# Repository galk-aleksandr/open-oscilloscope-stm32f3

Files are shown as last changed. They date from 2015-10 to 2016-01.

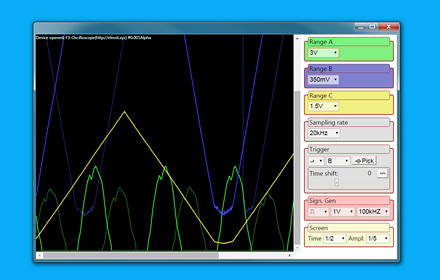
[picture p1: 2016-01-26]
chromoscope/small_tile.png

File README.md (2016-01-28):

##Open-Source Oscilloscope based on STM32F3-DISCOVERY board

Some ideas got from Tomasz Ostrowski's [Miniscope](http://tomeko.net/miniscope_v4/index.php?lang=en).
Tomasz has a bunch of ready-to-use-devices, and I have the only preliminary schematics and raw prototype.

The main idea is to build PC-oscilloscope. Hardware is ST Microelectronics development board
[STM32F3-DISCOVERY](http://www.st.com/web/catalog/tools/FM116/SC959/SS1532/PF254044) plus small additional board with simple protection circuits and basic voltage dividers.

###License:
[MIT](license.txt)

###Hardware variants
* Naked Discovery(Nucleo)
 * _No overvoltage protection_
 * Input voltage: 0..3V uni-polar
* [Shield board](#shield-board) + Discovery(Nucleo)
 * Overvoltage protection
 * Input voltage: 0..45V uni-polar
 * Input impedance ~1MOhm

###Features(Milestone 1):
* PC connectivity - USB
* Platform independent desktop(Chrome App)
* Minimal voltage resolution 46&mu;V
* Internal SYNC
* Simple signal generator (triangle, white noise)
* 12-bit sampling
* Channel GAIN up to x16
* Three channels
* Up to 5M samples/sec

###Features(Milestone 2):
* Extended signal generator(meander, sine wave, custom shape)
* Nucleo-F303RE board support
* External SYNC

###Shield board:
[PCB sources](https://github.com/elmot/open-oscilloscope-stm32f3/tree/schematics)(MIT license)

Schematics
Board

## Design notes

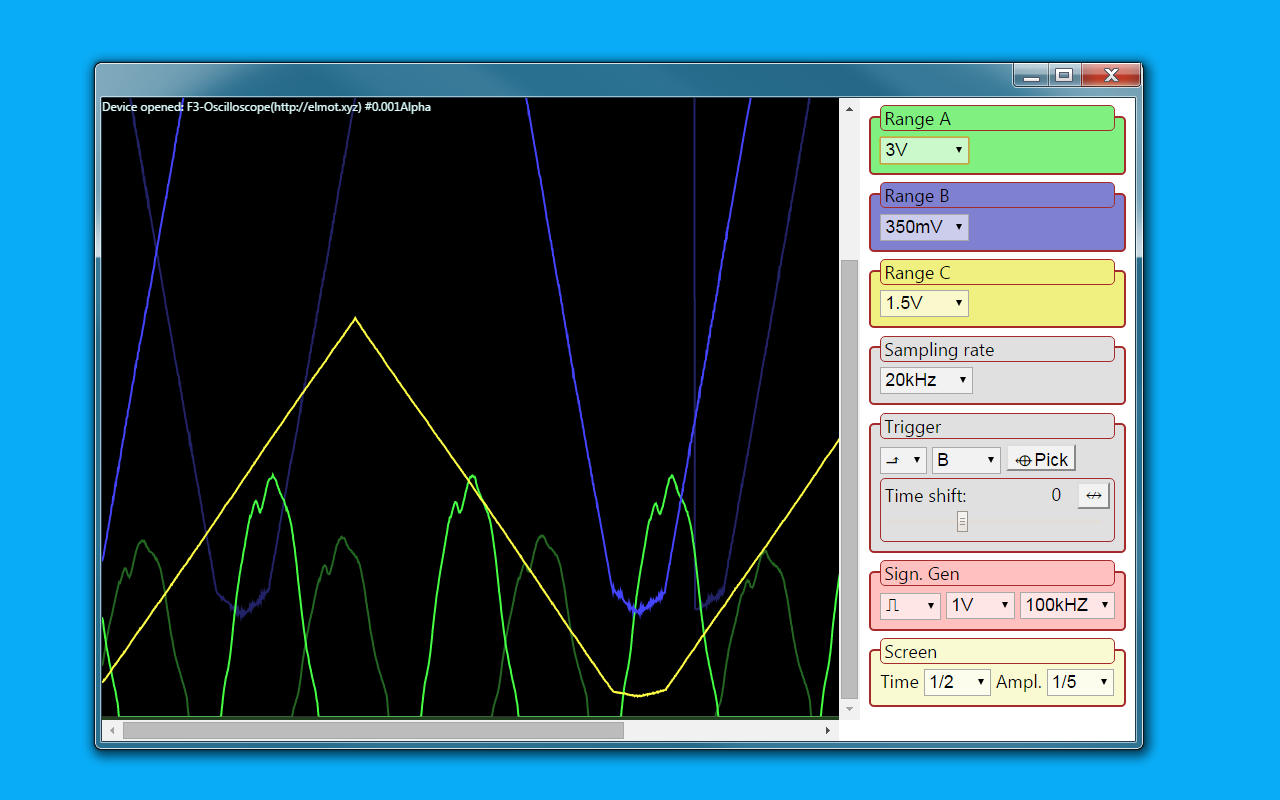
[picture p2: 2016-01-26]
chromoscope/screenshot.png

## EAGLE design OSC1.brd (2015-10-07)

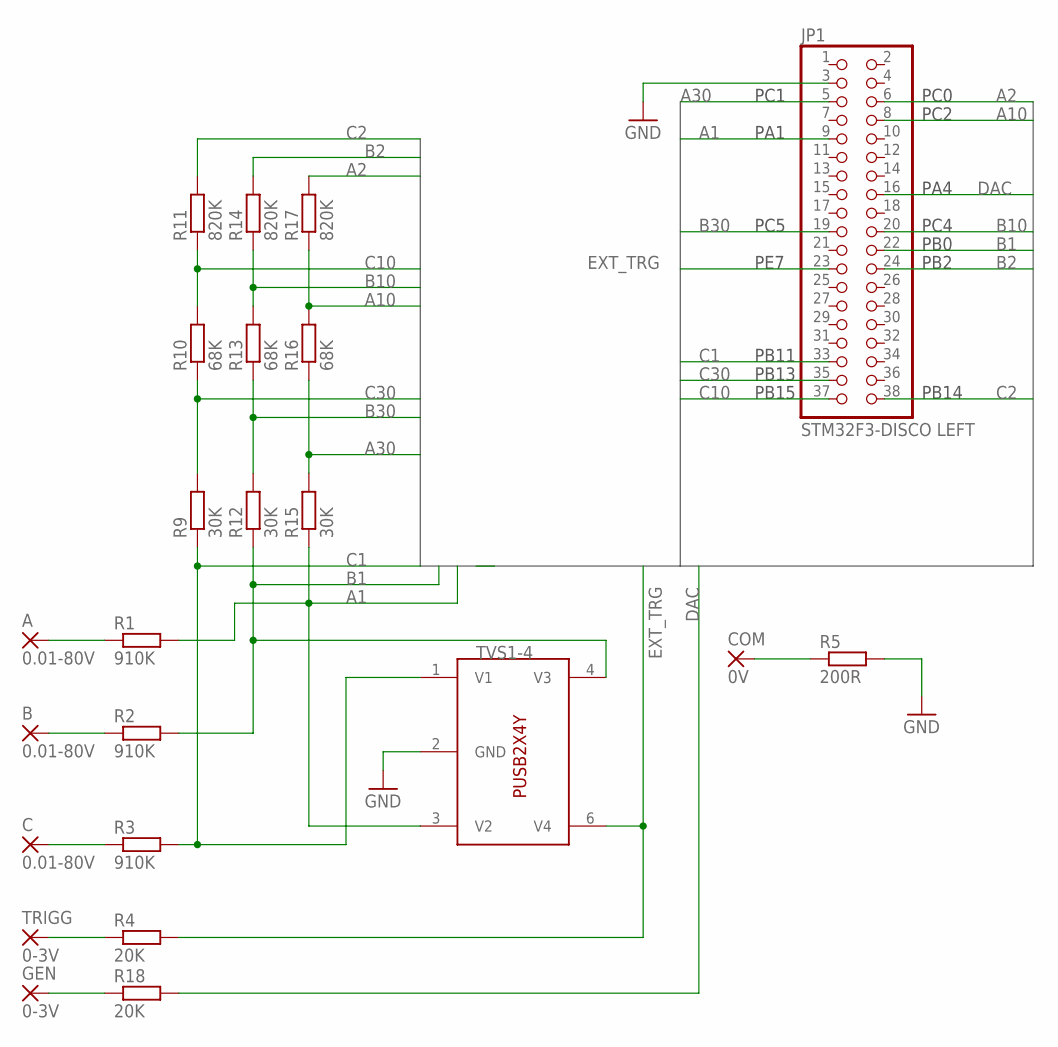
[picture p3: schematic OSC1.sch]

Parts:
A: 0.01-80V; 2,54/0,8
B: 0.01-80V; 2,54/0,8
C: 0.01-80V; 2,54/0,8
COM: 0V; 2,54/0,8
GEN: 0-3V; 2,54/0,8
JP1: STM32F3-DISCO LEFT; 2X19
R1, R2, R3: 910K; R1206
R4, R18: 20K; R1206
R5: 200R; R1206
R9, R12, R15: 30K; R1206
R10, R13, R16: 68K; R1206
R11, R14, R17: 820K; R1206
TRIGG: 0-3V; 2,54/0,8
TVS1-4: PUSB2X4Y; SOT363_PHILIPS

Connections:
A1: JP1.9, R1.2, R15.1, TVS1-4.3 (V2)
A2: JP1.6, R17.2
A10: JP1.8, R16.2, R17.1
A30: JP1.5, R15.2, R16.1
B1: JP1.22, R2.2, R12.1, TVS1-4.4 (V3)
B2: JP1.24, R14.2
B10: JP1.20, R13.2, R14.1
B30: JP1.19, R12.2, R13.1
C1: JP1.33, R3.2, R9.1, TVS1-4.1 (V1)
C2: JP1.38, R11.2
C10: JP1.37, R10.2, R11.1
C30: JP1.35, R9.2, R10.1
DAC: JP1.16, R18.2
EXT_TRG: JP1.23, R4.2, TVS1-4.6 (V4)
GND: JP1.3, R5.2, TVS1-4.2 (GND)
unnamed: COM.1, R5.1
unnamed: A.1, R1.1
unnamed: R4.1, TRIGG.1
unnamed: C.1, R3.1
unnamed: B.1, R2.1
unnamed: GEN.1, R18.1

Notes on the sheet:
PA1
PB11
PB0
PA4
PC1
PC0
PC2
PB2
PC4
PC5
PB13
PB14
PB15
PE7

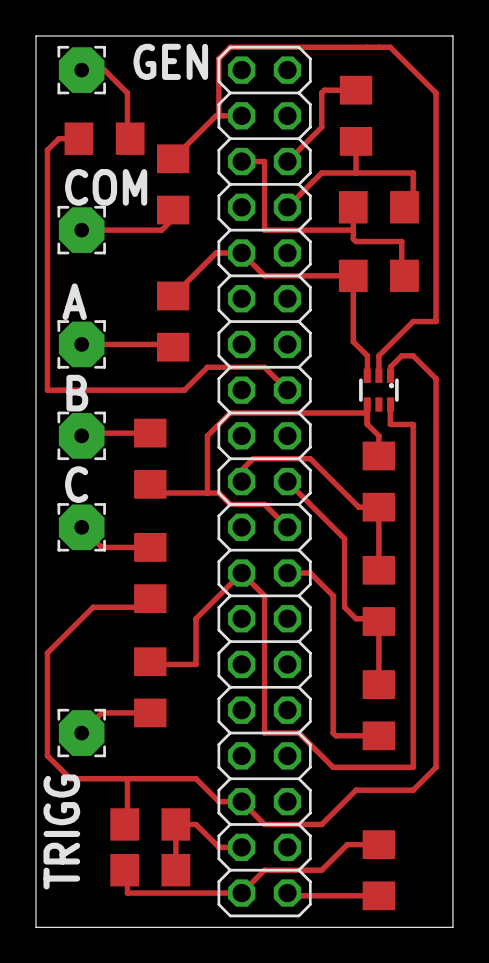
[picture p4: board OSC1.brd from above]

Board: 2 copper layers, 23.2 x 49.5 mm, 23 parts (0 on the bottom side), 21 nets.

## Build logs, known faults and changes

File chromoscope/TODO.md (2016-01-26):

## Firmware
* ADC sampling time
* get rid of vertical lines
* broken line if pre-trigger
* Trigger histeresis
* Shield board detection
* Config send
* External trigger?

## PC software
* External trigger
* Grid over canvas
* Measurements
* Help/Documentation
* Naked board config

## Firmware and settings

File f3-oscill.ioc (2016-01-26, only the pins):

Mcu.UserName=STM32F303VCTx
PA0.GPIO_Label=B1 [Blue PushButton]
PA0.Signal=GPIO_Input
PA1.GPIO_Label=OSCILLOSCOPE-A1[OPAMP1-VINP]
PA1.Signal=OPAMP1_VINP
PA11.GPIO_Label=DM
PA11.Signal=USB_DM
PA12.GPIO_Label=DP
PA12.Signal=USB_DP
PA13.GPIO_Label=SWDIO
PA13.Signal=SYS_JTMS-SWDIO
PA14.GPIO_Label=SWCLK
PA14.Signal=SYS_JTCK-SWCLK
PA2.Signal=OPAMP1_VOUT
PA3.Signal=USART2_RX
PA4.GPIO_Label=OSCILLOSCOPE-GEN[DAC-OUT1]
PA4.Signal=COMP_DAC1_group
PA5.GPIO_Label=SPI1_SCK [L3GD20_SCL/SPC]
PA5.Signal=SPI1_SCK
PA6.GPIO_Label=SPI1_MISO [L3GD20_SA0/SDO]
PA6.Signal=SPI1_MISO
PA7.GPIO_Label=SPI1_MISO [L3GD20_SDA/SDI/SDO]
PA7.Signal=SPI1_MOSI
PB0.GPIO_Label=OSCILLOSCOPE-B1[OPAMP3-VINP]
PB0.Signal=OPAMP3_VINP
PB1.Signal=OPAMP3_VOUT
PB11.GPIO_Label=OSCILLOSCOPE-C1[OPAMP4-VINP]
PB11.Signal=OPAMP4_VINP
PB12.Signal=OPAMP4_VOUT
PB13.GPIO_Label=OSCILLOSCOPE-C30
PB13.Signal=GPIO_Output
PB14.GPIO_Label=OSCILLOSCOPE-C2
PB14.Signal=GPIO_Output
PB15.GPIO_Label=OSCILLOSCOPE-C10
PB15.Signal=GPIO_Output
PB2.GPIO_Label=OSCILLOSCOPE-B2
PB2.Signal=GPIO_Output
PB3.GPIO_Label=SWO
PB3.Signal=SYS_JTDO-TRACESWO
PB6.GPIO_Label=I2C1_SCL [LSM303DLHC_SCL]
PB6.Signal=I2C1_SCL
PB7.GPIO_Label=I2C1_SDA [LSM303DLHC_SDA]
PB7.Signal=I2C1_SDA
PC0.GPIO_Label=OSCILLOSCOPE-A2
PC0.Signal=GPIO_Output
PC1.GPIO_Label=OSCILLOSCOPE-A30
PC1.Signal=GPIO_Output
PC14-OSC32_IN.GPIO_Label=OSC32_IN
PC14-OSC32_IN.Signal=RCC_OSC32_IN
PC15-OSC32_OUT.GPIO_Label=OSC32_OUT
PC15-OSC32_OUT.Signal=RCC_OSC32_OUT
PC2.GPIO_Label=OSCILLOSCOPE-A10
PC2.Signal=GPIO_Output
PC4.GPIO_Label=OSCILLOSCOPE-B10
PC4.Signal=GPIO_Output
PC5.GPIO_Label=OSCILLOSCOPE-B30
PC5.Signal=GPIO_Output
PD5.Signal=USART2_TX
PE0.GPIO_Label=MEMS_INT1 [L3GD20_INT1]
PE0.Signal=GPXTI0
PE1.GPIO_Label=MEMS_INT2 [L3GD20_DRDY/INT2]
PE1.Signal=GPXTI1
PE10.GPIO_Label=LD5 [Orange Led]
PE10.Signal=GPIO_Output
PE11.GPIO_Label=LD7 [Green Led]
PE11.Signal=GPIO_Output
PE12.GPIO_Label=LD9 [Blue Led]
PE12.Signal=GPIO_Output
PE13.GPIO_Label=LD10 [Red Led]
PE13.Signal=GPIO_Output
PE14.GPIO_Label=LD8 [Orange Led]
PE14.Signal=GPIO_Output
PE15.GPIO_Label=LD6 [Green Led]
PE15.Signal=GPIO_Output
PE2.GPIO_Label=DRDY [LSM303DLHC_DRDY]
PE2.Signal=GPXTI2
PE3.GPIO_Label=CS_I2C/SPI [L3GD20_CS_I2C/SPI]
PE3.Signal=GPIO_Output
PE4.GPIO_Label=MEMS_INT3 [LSM303DLHC_INT1]
PE4.Signal=GPXTI4
PE5.GPIO_Label=MEMS_INT4 [LSM303DLHC_INT2]
PE5.Signal=GPXTI5
PE7.GPIO_Label=OSCILLOSCOPE-EXT_SYNC[COMP4_INP]
PE7.Signal=COMP4_INP
PE8.GPIO_Label=LD4 [Blue Led]
PE8.Signal=GPIO_Output
PE9.GPIO_Label=LD3 [Red Led]
PE9.Signal=GPIO_Output
PF0-OSC_IN.GPIO_Label=OSC_IN
PF0-OSC_IN.Signal=RCC_OSC_IN
PF1-OSC_OUT.GPIO_Label=OSC_OUT
PF1-OSC_OUT.Signal=RCC_OSC_OUT

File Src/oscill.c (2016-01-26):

#include "string.h"
#include "stdbool.h"
#include "oscill.h"
#include "usbd_oscill_if.h"
#include "arm_math.h"

uint16_t bufferA[FRAME_SIZE + 1];
uint16_t bufferB[FRAME_SIZE + 1];
uint16_t bufferC[FRAME_SIZE + 1];
uint16_t bufferAT[FRAME_SIZE + 1];
uint16_t bufferBT[FRAME_SIZE + 1];
uint16_t bufferCT[FRAME_SIZE + 1];

uint16_t bufferD[FRAME_SIZE + 1];

volatile bool ongoingFrameClear = false;
/* TODO
trig.ch
            <!--<option value="E" DISABLED>Ext</option>-->
Empty frames after param change
*/
char triggerType = 'R';
char triggerChannel = 'Z';
int triggerTimeShift = 0;
int triggerLevel = 0;
volatile uint32_t triggerLevelReg2 = 0xFFFFFFFF;

ADC_HandleTypeDef * getTriggerADC(){
	switch(triggerChannel) {
		case 'B': return &hadc3;
		case 'C': return &hadc4;
	}
	return &hadc1;
}
static void setupTrigger() {
	hadc1.Instance->CFGR &= ~ADC_CFGR_AWD1EN;
	hadc3.Instance->CFGR &= ~ADC_CFGR_AWD1EN;
	hadc4.Instance->CFGR &= ~ADC_CFGR_AWD1EN;
	if(triggerChannel == 'Z') {
			bufferA[0] |= FLAG_TRIGGERED;
			bufferB[0] |= FLAG_TRIGGERED;
			bufferC[0] |= FLAG_TRIGGERED;
	} else {
		bufferA[0] &= ~FLAG_TRIGGERED;
		bufferB[0] &= ~FLAG_TRIGGERED;
		bufferC[0] &= ~FLAG_TRIGGERED;
		__HAL_TIM_SetAutoreload(&htim3, FRAME_SIZE + triggerTimeShift);
		__HAL_TIM_SetCounter(&htim3, 0);
		ADC_HandleTypeDef * hadc = getTriggerADC();
		if(triggerType == 'R') {
			hadc->Instance->TR1 = __HAL_ADC_TRX_HIGHTHRESHOLD(0xFFF) | triggerLevel;
			triggerLevelReg2 = __HAL_ADC_TRX_HIGHTHRESHOLD(triggerLevel);
		} else {
			hadc->Instance->TR1 = __HAL_ADC_TRX_HIGHTHRESHOLD(triggerLevel);
			triggerLevelReg2 = __HAL_ADC_TRX_HIGHTHRESHOLD(0xFFF) | triggerLevel;
		}
		hadc->Instance->CFGR |= ADC_CFGR_AWD1EN;
	}
}

void setTriggerType(char sign) {
	triggerType = sign;
	setupTrigger();
}

void setTriggerChannel(char sign) {
	triggerChannel = sign;
	setupTrigger();
}

int parseDecimal(char* buf, size_t len) {
	bool minus = false;
	int val = 0;
	for(int i = 0; i < len; i++) {
	  if(buf[i]  == '-') {
			minus = true; 
		} else if(buf[i]  >= '0' && buf[i]  <= '9' ) {
			val = val*10 + buf[i] -'0';
		} else break;
	}
	return minus ? -val : val;
}

void setTriggerLevel(char *value, size_t length) {
	triggerLevel = parseDecimal(value,length);
	setupTrigger();
}

void setTriggerTimeShift(char *value, size_t length) {
	triggerTimeShift = parseDecimal(value,length);
	setupTrigger();
}




void channelTrigger() {
	HAL_TIM_Base_Stop(&htim1);
	HAL_TIM_Base_Stop(&htim3);
	int counter = hadc1.DMA_Handle->Instance->CNDTR;

	memcpy(&bufferAT[1],&bufferA[FRAME_SIZE - counter + 1], counter * 2);
	memcpy(&bufferAT[counter + 1],&bufferA[1], (FRAME_SIZE - counter) * 2);
	memcpy(&bufferBT[1],&bufferB[FRAME_SIZE - counter + 1], counter * 2);
	memcpy(&bufferBT[counter + 1],&bufferB[1], (FRAME_SIZE - counter) * 2);
	memcpy(&bufferCT[1],&bufferC[FRAME_SIZE - counter + 1], counter * 2);
	memcpy(&bufferCT[counter + 1],&bufferC[1], (FRAME_SIZE - counter) * 2);
	bufferAT[0] = FLAG_NEW | FLAG_TRIGGERED;
	bufferBT[0] = FLAG_NEW | FLAG_TRIGGERED;
	bufferCT[0] = FLAG_NEW | FLAG_TRIGGERED;
  if( ongoingFrameClear) {
		bufferAT[0] |= FLAG_CLEAR;
		bufferBT[0] |= FLAG_CLEAR;
		bufferCT[0] |= FLAG_CLEAR;
	}
	HAL_TIM_Base_Start(&htim1);
	
	setupTrigger();
}

void HAL_ADC_LevelOutOfWindowCallback(ADC_HandleTypeDef* hadc) {
	if(triggerLevelReg2 == 0xFFFFFFFF) {
		ongoingFrameClear = false;
		HAL_TIM_Base_Start(&htim3);
		hadc->Instance->CFGR &= ~ADC_CFGR_AWD1EN;
	} else {
		hadc->Instance->TR1 = triggerLevelReg2;
		triggerLevelReg2 = 0xFFFFFFFF;
	}
}

void initOscill() {
		{/*Fix cubeMX bug */
		hopamp4.Init.NonInvertingInput = OPAMP_NONINVERTINGINPUT_VP3;
		HAL_OPAMP_Init(&hopamp4);
	}
	HAL_ADC_Start_DMA(&hadc1, (uint32_t*)&bufferA[1], FRAME_SIZE);
	HAL_ADC_Start_DMA(&hadc3, (uint32_t*)&bufferB[1], FRAME_SIZE);
	HAL_ADC_Start_DMA(&hadc4, (uint32_t*)&bufferC[1], FRAME_SIZE);
	HAL_TIM_Base_Start(&htim1);
	HAL_TIM_Base_Start(&htim2);
	HAL_OPAMP_Start(&hopamp1);
	HAL_OPAMP_Start(&hopamp3);
	HAL_OPAMP_Start(&hopamp4);

  __HAL_TIM_CLEAR_IT(&htim3, TIM_IT_UPDATE);
	__HAL_TIM_ENABLE_IT(&htim3, TIM_IT_UPDATE);
	
	bufferAT[0] = FLAG_TRIGGERED | FLAG_CLEAR;
	bufferBT[0] = FLAG_TRIGGERED | FLAG_CLEAR;
	bufferCT[0] = FLAG_TRIGGERED | FLAG_CLEAR;
	setupTrigger();
}

static void clearKeyFrames()
{
	bufferAT[0] |= FLAG_CLEAR | FLAG_NEW;
	bufferBT[0] |= FLAG_CLEAR | FLAG_NEW;
	bufferCT[0] |= FLAG_CLEAR | FLAG_NEW;
	ongoingFrameClear = true;
}
typedef struct {
	__IO uint32_t * div2ODR;
	uint32_t div2mask;
	__IO uint32_t * div10ODR;
	uint32_t div10mask;
	__IO uint32_t * div30ODR;
	uint32_t div30mask;
} VoltDivBits;

static const VoltDivBits divBits[3] = {
{
	&OSCILLOSCOPE_A2_GPIO_Port->ODR , OSCILLOSCOPE_A2_Pin, 
	&OSCILLOSCOPE_A10_GPIO_Port->ODR, OSCILLOSCOPE_A10_Pin, 
	&OSCILLOSCOPE_A30_GPIO_Port->ODR, OSCILLOSCOPE_A30_Pin
},
{
	&OSCILLOSCOPE_B2_GPIO_Port->ODR , OSCILLOSCOPE_B2_Pin, 
	&OSCILLOSCOPE_B10_GPIO_Port->ODR, OSCILLOSCOPE_B10_Pin, 
	&OSCILLOSCOPE_B30_GPIO_Port->ODR, OSCILLOSCOPE_B30_Pin
},
{
	&OSCILLOSCOPE_C2_GPIO_Port->ODR, OSCILLOSCOPE_C2_Pin, 
	&OSCILLOSCOPE_C10_GPIO_Port->ODR, OSCILLOSCOPE_C10_Pin, 
	&OSCILLOSCOPE_C30_GPIO_Port->ODR, OSCILLOSCOPE_C30_Pin
}

};

void setDiv(char channel_letter, char d) {
	int chIdx = channel_letter - 'a';
	if(chIdx >=0 && chIdx < 4) {
		switch(d) {
			case '0':
				* divBits[chIdx].div2ODR  |= divBits[chIdx].div2mask;
				* divBits[chIdx].div10ODR |= divBits[chIdx].div10mask;
				* divBits[chIdx].div30ODR |= divBits[chIdx].div30mask;
				break;
			case '1':
				* divBits[chIdx].div2ODR  &= ~divBits[chIdx].div2mask;;
				* divBits[chIdx].div10ODR |= divBits[chIdx].div10mask;
				* divBits[chIdx].div30ODR |= divBits[chIdx].div30mask;
				break;
			case '2':
				* divBits[chIdx].div2ODR  |= divBits[chIdx].div2mask;
				* divBits[chIdx].div10ODR &= ~divBits[chIdx].div10mask;
				* divBits[chIdx].div30ODR |= divBits[chIdx].div30mask;
				break;
			case '3':
				* divBits[chIdx].div2ODR  |= divBits[chIdx].div2mask;
				* divBits[chIdx].div10ODR |= divBits[chIdx].div10mask;
				* divBits[chIdx].div30ODR &= ~divBits[chIdx].div30mask;
				break;
		}
	}
	clearKeyFrames();
}

void setGain(char opamp_letter, char g) {
	OPAMP_HandleTypeDef * opamp;
	switch(opamp_letter) {
		case	'a': opamp = &hopamp1; break;
		case	'b': opamp = &hopamp3; break;
		case	'c': opamp = &hopamp4; break;
		default: return;
	}
	opamp->Init.Mode = OPAMP_PGA_MODE;
	switch(g) {
			case '0': 
					opamp->Init.PgaGain = OPAMP_PGA_GAIN_2;
				break;
			case '1': 
					opamp->Init.PgaGain = OPAMP_PGA_GAIN_4;
				break;
			case '2':
					opamp->Init.PgaGain = OPAMP_PGA_GAIN_8; 
				break;
			case '3': 
					opamp->Init.PgaGain = OPAMP_PGA_GAIN_16; 
				break;
			default: 
					opamp->Init.Mode = OPAMP_FOLLOWER_MODE;
				break;
	}
	HAL_OPAMP_Init(opamp);
	HAL_OPAMP_Start(opamp);
	clearKeyFrames();
}

typedef struct {
	uint16_t prescaler;
	uint16_t arr;
	uint16_t samplingTime;
} TimeCoeff;
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

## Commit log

2015-10-07 Board retraced
    [OSC1.brd, OSC1.sch]
2016-01-26 FW - base config support, OPAMP Follower mode support
    [exampleConfig.txt, nakedConfig.txt, shieldedConfig.txt]
2016-01-26 Generator support + fixes
    [f3-oscill.ioc, oscill.c]
